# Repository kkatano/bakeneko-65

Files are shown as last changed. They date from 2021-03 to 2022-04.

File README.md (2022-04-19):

# Bakeneko 65 V3

A simple 65% keyboard for DIYers. This project is a special homage to TGR x Singa UNIKORN 60 and OTD 356 Mini. See also the [introduction video](https://youtu.be/o677NcIUri4).

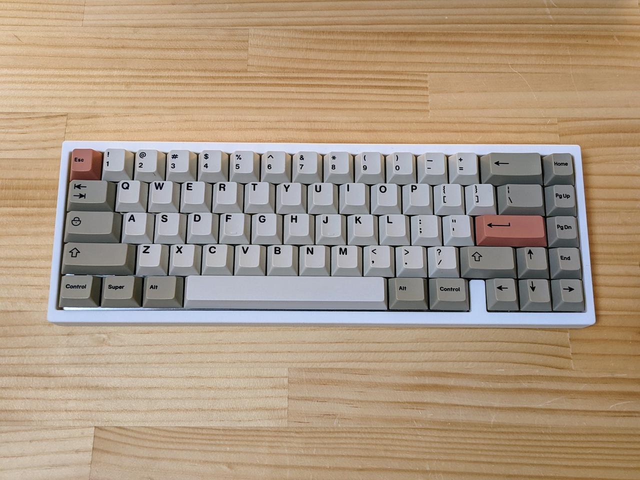
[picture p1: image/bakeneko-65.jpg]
Bakeneko 65


## Features

- Single piece tray case
- O-ring gasket mount (Friction fit)
- [Unified Daughterboard](https://github.com/ai03-2725/Unified-Daughterboard)
- QMK firmware and VIA
- PCB designed with KiCAD 5.1.4

## Layouts

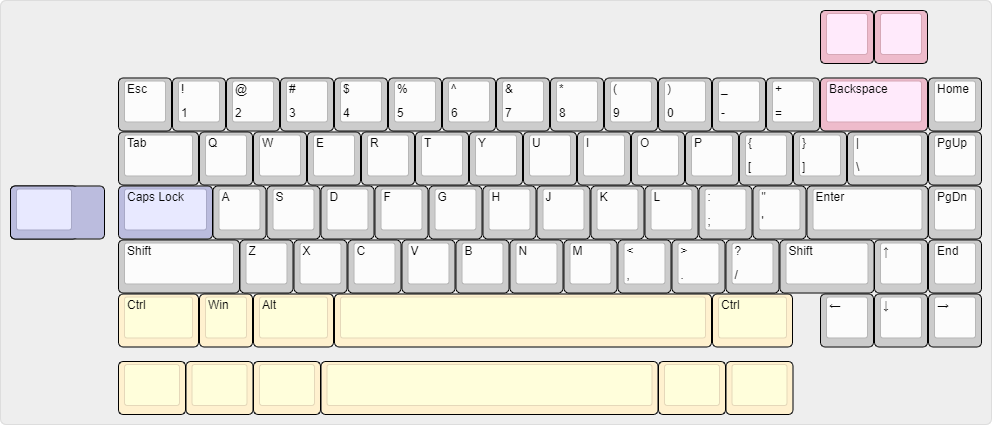
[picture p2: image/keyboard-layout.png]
Bakeneko 65 layouts


## Specs

- Dimensions: 315 x 110 x 30mm
- Front height: 18.5mm
- Home row height: 31mm(with GMK keycaps and bumpons)
- Typing angle: 6 degree
- Weight:
  - PLA Case: 390g
  - Aluminum Case: 760g
- O-ring gasket: VMQ-50(Silicone 50 duro) AS568-264

## Notes
- Old files (v1) are no longer available. See [geekhack post](https://geekhack.org/index.php?topic=107316.msg2974824#msg2974824) for the context
- The use of old (v1) mounting posts is prohibited
- All files are to be used at your own risk
- As for stabilizers, only PCB snap ins are supported

## Resources

- Documents: https://drive.google.com/drive/folders/1tddSihOS8Pgf1lTQOjHohYCl8efxXIeH
  - Parts guide and other useful information
  - Will be added and updated as needed
- Discord: https://discord.gg/fMY96TeEwV
  - Have fun with community members
  - Talk about Bakeneko builds and mods, and share your works
  - You can also contact me from there

## Special thanks to

- **Elaine** for [Unikorn](https://geekhack.org/index.php?topic=98587.50). Allowed me to publish the Unikorn-inspired case as open source and encouraged me
- Of course, I also show my respect and gratitude to **yuktsi**
- **coarse** for PCB review and kind support. His great work has refined the PCB well

## Also I should mention

- **OTD** for 356 Mini. Origin of O-ring gasket mount style
- **Evy** for [Plain60 series](https://github.com/evyd13/plain60-c). I used it as a reference for my PCB design. They also answered my miscellaneous questions
- **ai03** for [MX_Alps_Hybrid](https://github.com/ai03-2725/MX_Alps_Hybrid). Also got a lot of help from his discord server
- **overset** for [JP01](https://github.com/overset/JP01). The idea of publishing the case design on Onshape. After seeing their great work I switched from fusion360 to Onshape
- **Rhuk** gave me a lot of advice on keyboard design and manufacturing
- **Maker Keyboards** suggested adding a plate cutout to remove the PCB using a keycap puller
- And many community members for giving me advice and feedback, thanks!

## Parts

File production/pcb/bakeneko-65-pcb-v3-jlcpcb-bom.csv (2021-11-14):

Designator | Comment | Footprint | LCSC Part #
C1 C2 C3 | 0.1u | Capacitor_SMD:C_0805_2012Metric | C49678
C4 | 10u | Capacitor_SMD:C_0805_2012Metric | C15850
C5 C6 | 22p | Capacitor_SMD:C_0805_2012Metric | C1804
C7 | 1u | Capacitor_SMD:C_0805_2012Metric | C28323
D68 D67 D66 D65 D64 D63 D62 D61 D60 D59 D58 D57 D56 D55 D54 D53 D52 D51 D50 D49 D48 D47 D46 D45 D44 D43 D42 D41 D40 D39 D38 D37 D36 D35 D34 D33 D32 D31 D30 D29 D28 D27 D26 D25 D24 D23 D22 D21 D20 D19 D18 D17 D16 D15 D14 D13 D12 D11 D10 D9 D8 D7 D6 D5 D4 D3 D2 D1 | 1N4148 | Diode_SMD:D_SOD-123 | C81598
F1 | 500mA | Fuse:Fuse_1206_3216Metric | C70076
J1 | JST SH 4-pin | Connector_JST:JST_SH_SM04B-SRSS-TB_1x04-1MP_P1.00mm_Horizontal | C160404
R1 R4 | 10k | Resistor_SMD:R_0805_2012Metric | C17414
R2 R3 | 22 | Resistor_SMD:R_0805_2012Metric | C17561
SW1 | Reset | Button_Switch_SMD:SW_SPST_TL3342 | C318884
U1 | SRV05-4 | Package_TO_SOT_SMD:SOT-23-6 | C85364
U2 | ATmega32U4-AU | Package_QFP:TQFP-44_10x10mm_P0.8mm | C44854
Y1 | 16MHz | Crystal:Crystal_SMD_3225-4Pin_3.2x2.5mm | C13738

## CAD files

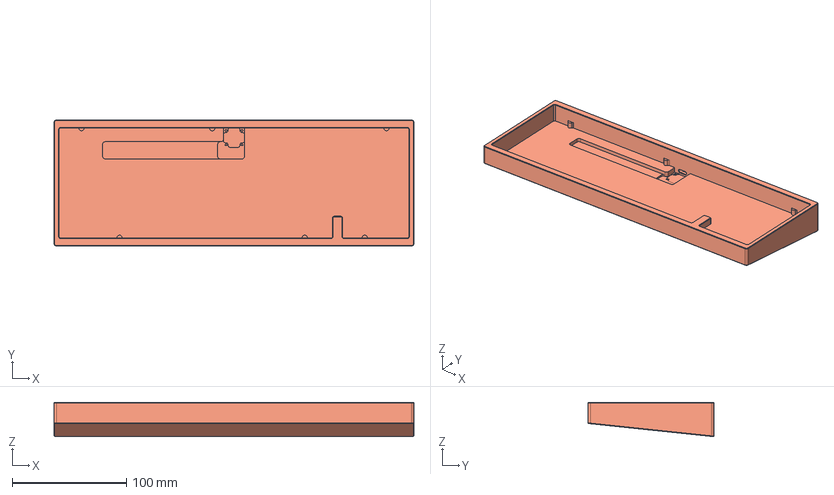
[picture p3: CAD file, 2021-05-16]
case-pla/bakeneko-65-pla.step
314.8 x 110.2 x 30.0 mm

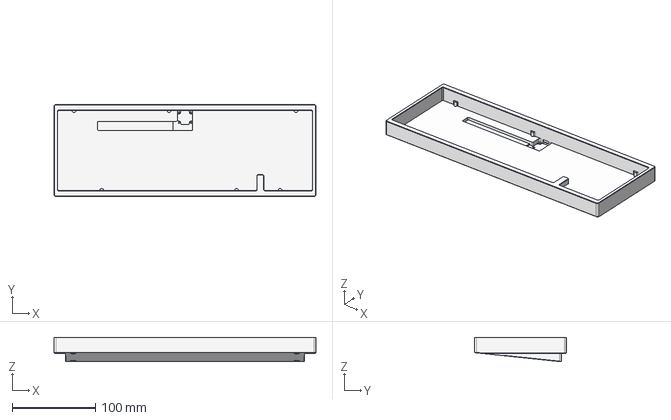
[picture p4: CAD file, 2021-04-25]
case/aluminum/bakeneko-65-case.step
314.8 x 110.2 x 29.4 mm

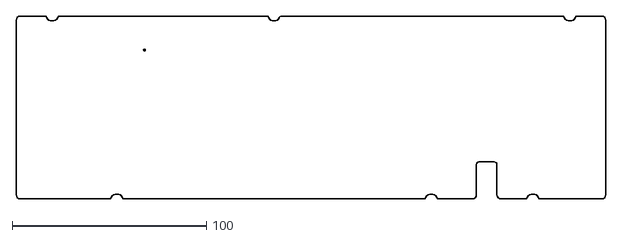
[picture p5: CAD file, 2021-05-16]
pcb/pcb-outline.dxf
303.8 x 94.2

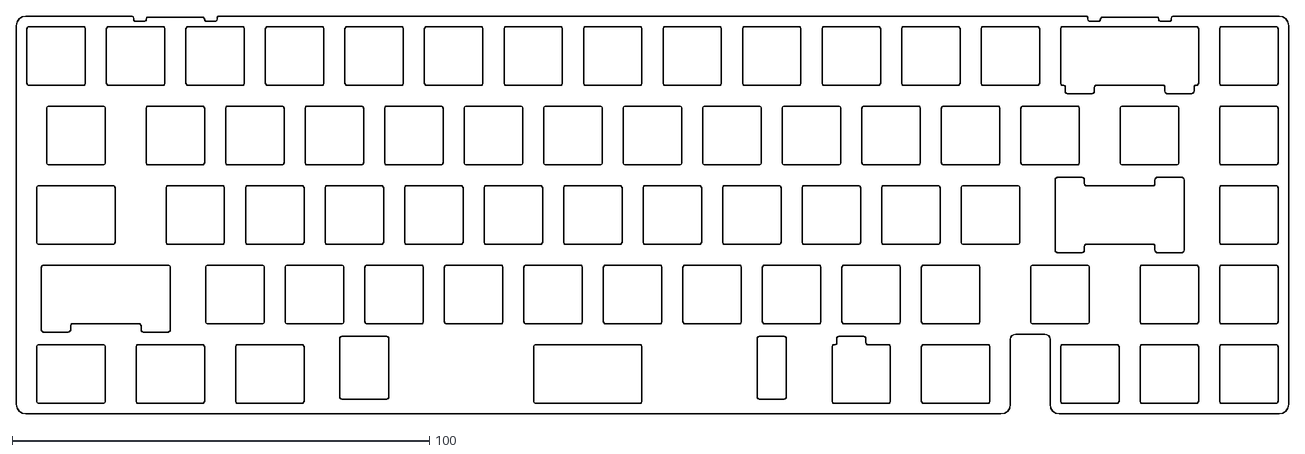
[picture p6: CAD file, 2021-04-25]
plate/bakeneko-65-plate.dxf
304.8 x 95.2

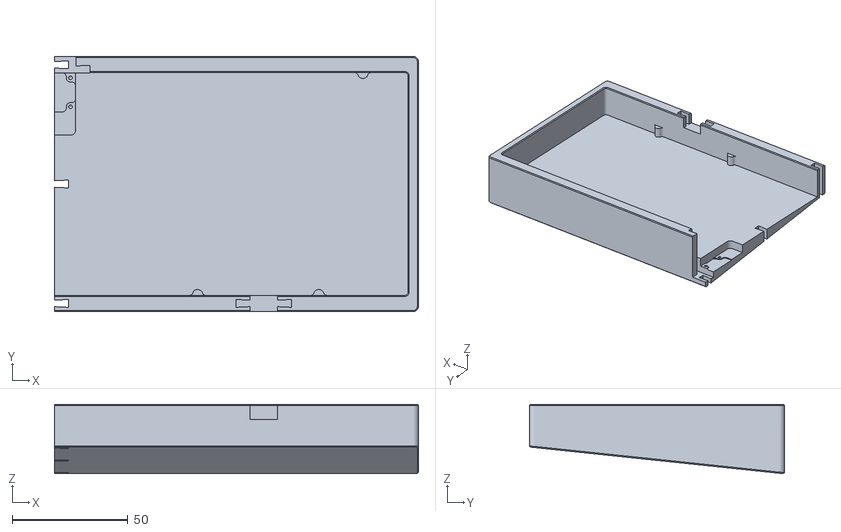
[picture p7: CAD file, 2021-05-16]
case-pla/bakeneko-65-pla-split-right.stl
157.3 x 110.2 x 30.0

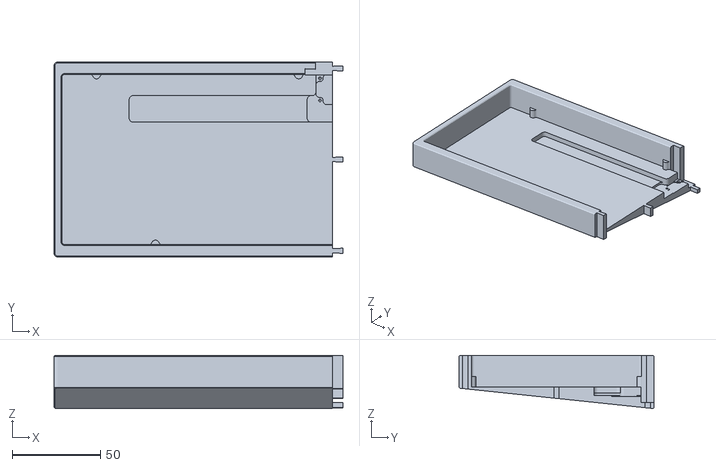
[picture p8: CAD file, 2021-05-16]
case-pla/bakeneko-65-pla-split-left.stl
163.4 x 110.2 x 30.0

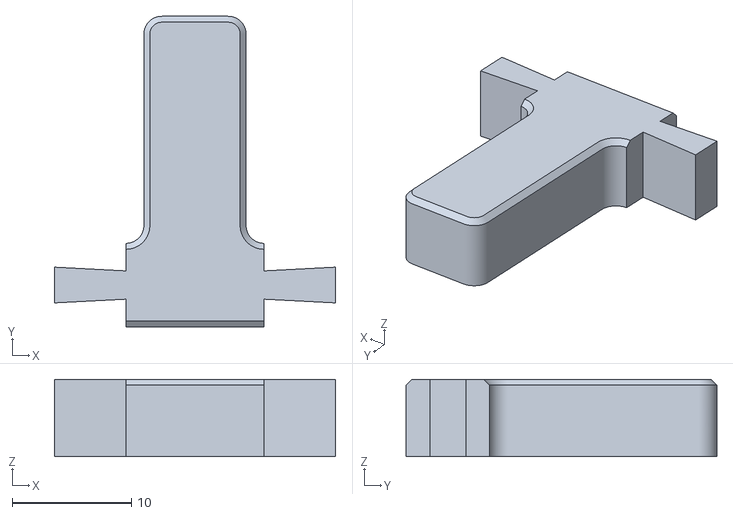
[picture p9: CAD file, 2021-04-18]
case-pla/bakeneko-65-pla-split-blocker.stl
23.6 x 26.1 x 6.50

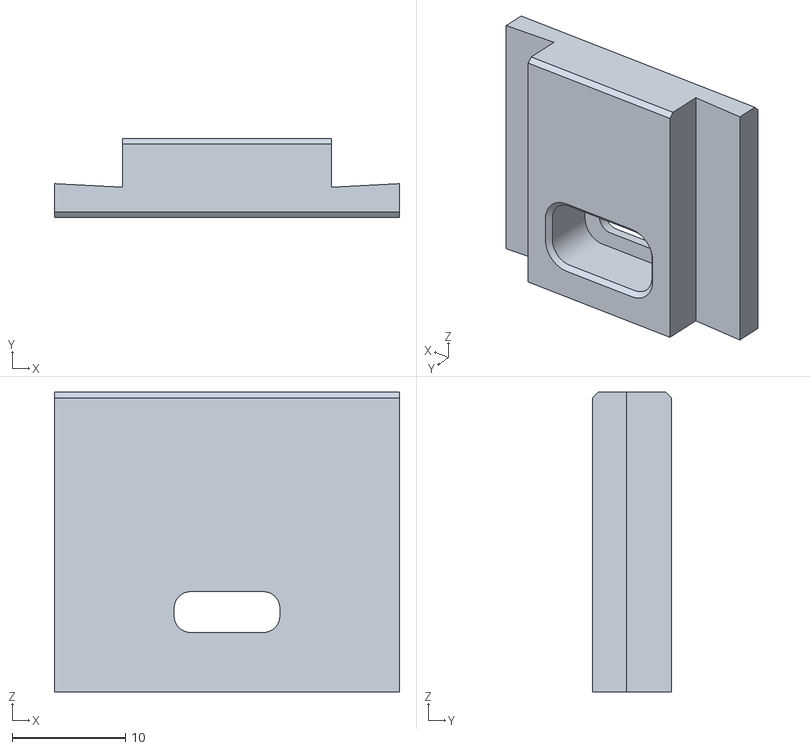
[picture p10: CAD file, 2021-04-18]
case-pla/bakeneko-65-pla-split-usb.stl
30.5 x 7.00 x 26.5

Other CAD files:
case/bakeneko-65-case.step

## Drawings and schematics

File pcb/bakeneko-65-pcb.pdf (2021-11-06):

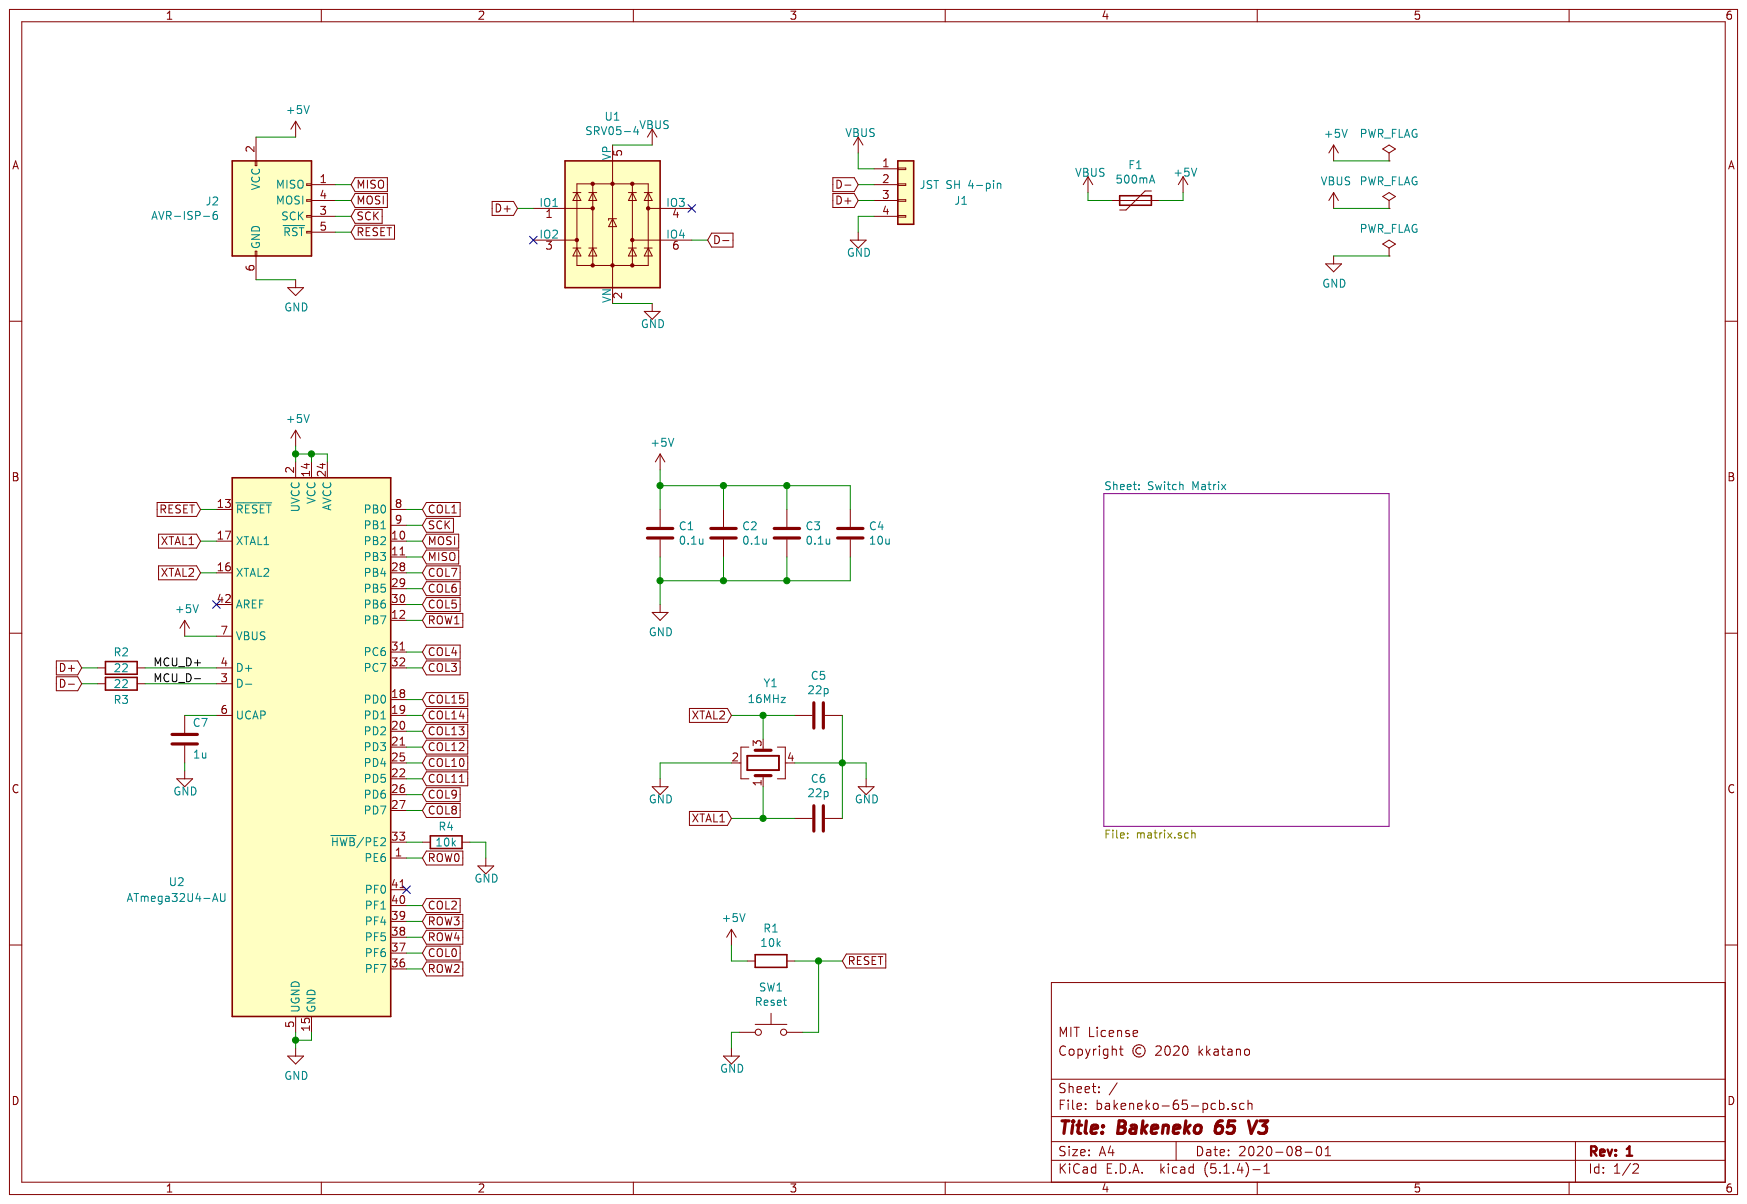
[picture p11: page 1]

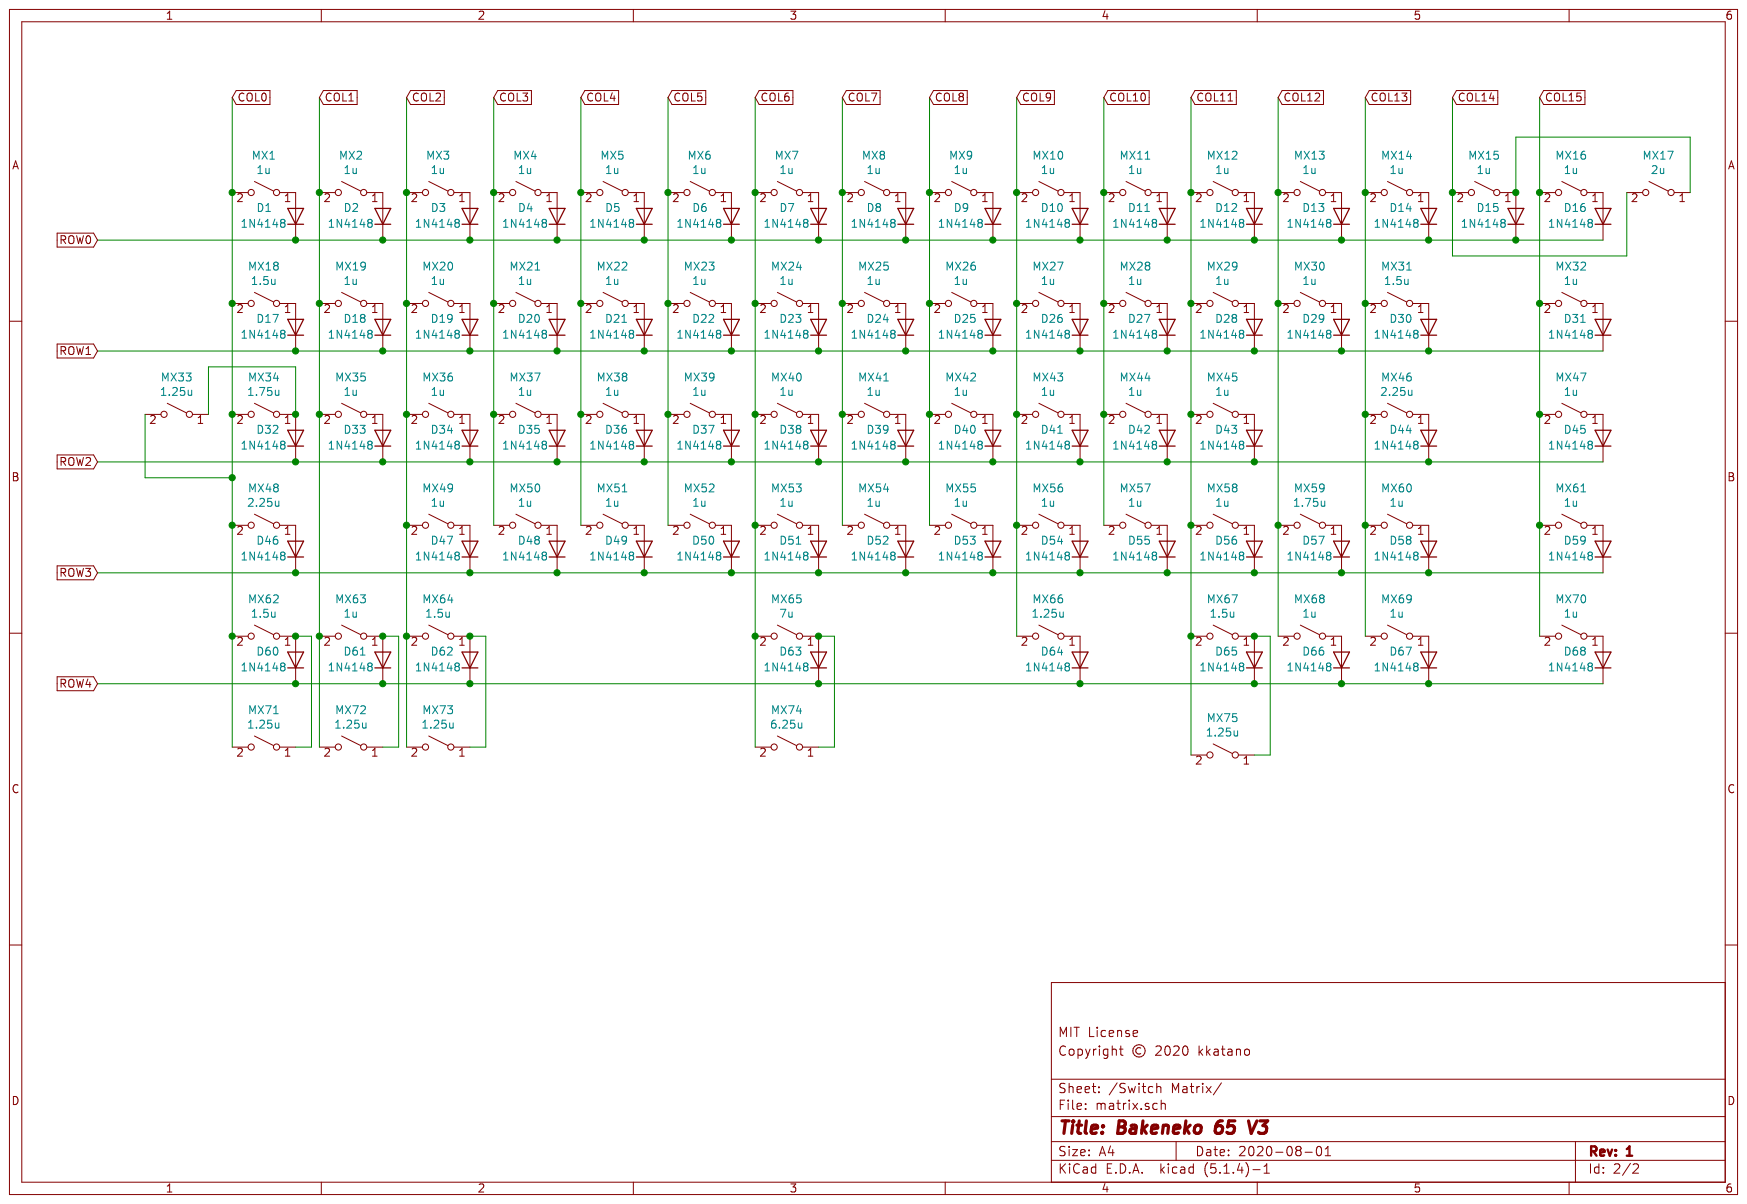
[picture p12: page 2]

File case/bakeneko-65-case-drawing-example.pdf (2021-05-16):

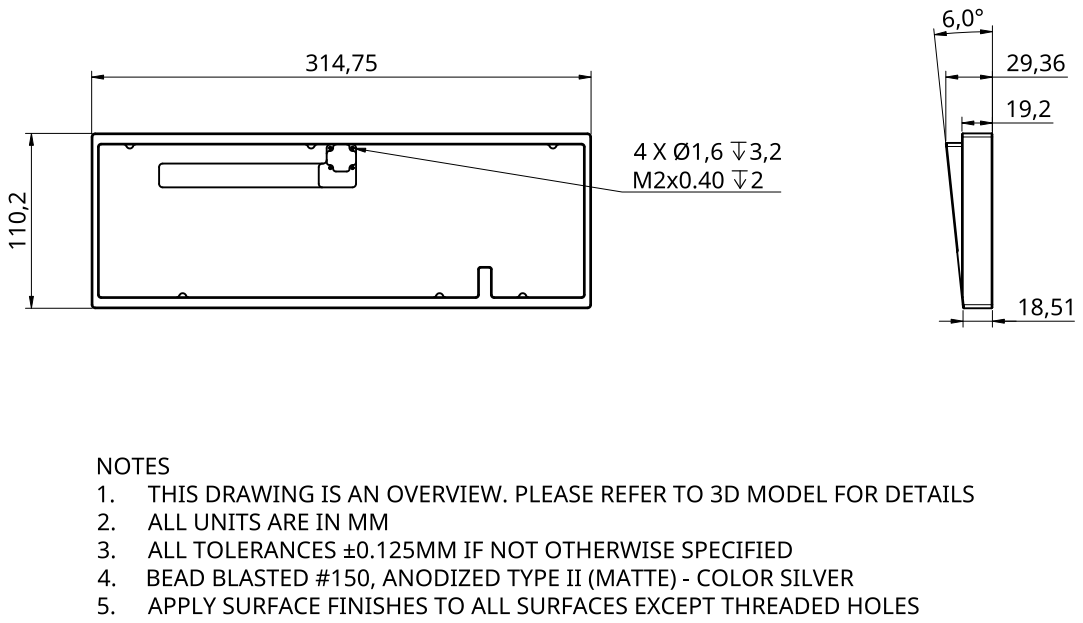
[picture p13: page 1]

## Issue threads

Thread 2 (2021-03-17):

discord-cannot accept invitation

xiaojia998, 2021-03-17:
discord-Invitation link seems to be expired, can't join, is it possible to x-invitation link now

kkatano, 2021-03-17:
Can you join via the following link?
https://discord.gg/fMY96TeEwV

xiaojia998, 2021-03-18:
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
Unable to accept invitation

xiaojia998, 2021-03-18:
> 您可以通过以下链接加入吗？
> https://discord.gg/fMY96TeEwV

Successfully joined, thanks

kkatano, 2021-03-18:
Thanks!

Closed 2021-03-18.

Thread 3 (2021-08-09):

There's no fullsize .STL for the case. Here it is

heckkeysxyz, 2021-08-09:
[FullCaseForBakeneko60STL.zip](https://github.com/kkatano/bakeneko-65/files/6951825/FullCaseForBakeneko60STL.zip)

I took the .STP/.STEP file and uploaded it to fusion, saved as an STL (Binary) with high refinement

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

Don't worry. Its all to scale. You can do this with an online .step to .stl converter if you'd like to. same exact dimensions as noted in the attached photo

Minimum Printer size to print this is like 300x150mm on the bed if you have a printer that dimension for some reason

kkatano, 2022-01-20:
Sorry for super delayed response, and Thanks for making the STL. I would like to incorporate it, but currently I am thinking about how to maintain this project. For example, if someone gives me such a suggestion, should I test it myself before incorporating it, etc.

I'm sorry, but I would appreciate it if you could wait until i reach a conclusion

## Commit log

2021-02-01 Update README.md Added JLC PCB Tutorial
2021-02-04 Removed JLC PCB Tutorial
2021-02-13 Initialize FR4 plate project
    [bakeneko-65-fr4-plate.kicad_pcb, bakeneko-65-fr4-plate.sch]
2021-02-13 Update PCB KiCAD project
    [bakeneko-65-pcb.kicad_pcb, matrix.sch, pcb-outline.dxf]
2021-02-13 Remove ISP
    [bakeneko-65-pcb.sch]
2021-02-13 Update board outline
    [bakeneko-65-pcb.kicad_pcb]
2021-02-13 Change JST port position
    [bakeneko-65-pcb.kicad_pcb]
2021-02-13 Remove old files
    [bakeneko-65.step]
2021-02-13 Update PCB readme
2021-02-14 Add PLA case
    [bakeneko-65-left.stl, bakeneko-65-right.stl, bakeneko-65-usb.stl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]
2021-02-14 Add aluminum case
    [bakeneko-65-case.step, bakeneko-65-weight.step]
2021-02-19 Update PLA case
    [bakeneko-65-left.stl, bakeneko-65-right.stl, bakeneko-65-usb.stl]
2021-03-07 Update aluminum case
    [bakeneko-65-case.step, bakeneko-65-weight.step]
2021-03-07 Update plate
    [bakeneko-65-fr4-plate.kicad_pcb, bakeneko-65-plate.dxf, layout-ansi.dxf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]
2021-04-18 Update pcb image
2021-04-25 Update case
    [bakeneko-65-case.step]
2021-04-25 Remove plate dxf
    [layout-ansi.dxf, layout-splitbs-7uspacebar.dxf]
2021-05-16 Update PCB
    [bakeneko-65-pcb.kicad_pcb, bakeneko-65-pcb.sch, pcb-outline.dxf]
2021-06-20 Add production files
    [bakeneko-65-pcb-v3-jlcpcb-bom.csv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]
2021-11-06 Update sch
    [bakeneko-65-pcb.sch, matrix.sch]
2021-11-14 Update production files
    [bakeneko-65-pcb-v3-jlcpcb-bom.csv]
